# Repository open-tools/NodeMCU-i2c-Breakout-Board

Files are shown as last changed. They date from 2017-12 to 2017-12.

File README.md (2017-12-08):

# NodeMCU I²C and 1-Wire Breakout Board

Have you  ever tried connecting more than one I²C device to a NodeMCU board? While I²C and 1-wire are designed to allow dozens of devices connected to the same bus, most boards - including the NodeMCU - provide only one pin for the I²C lines (SCL and SDA). To connect multiple I²C devices, one usually needs to resolve to clumsy breadboards.

This board is a simple, small breakout board for the NodeMCU, which is attached to only one side of the NodeMCU. It provides multiple I²C and 1-wire connections. The pin order of the I²C connectors is the one used by most I²C sensors:
* VCC
* GND
* SCL
* SDA

Please note that the SparkFun sensors use a different order!

The pin order of the 1-Wire connectors is:
* GND
* DATA
* VCC

One can solder either male or female pin headers to the breakout board and connect the sensors using Dupont wires, or use female pin headers with the sensors directly plugged into the breakout board.

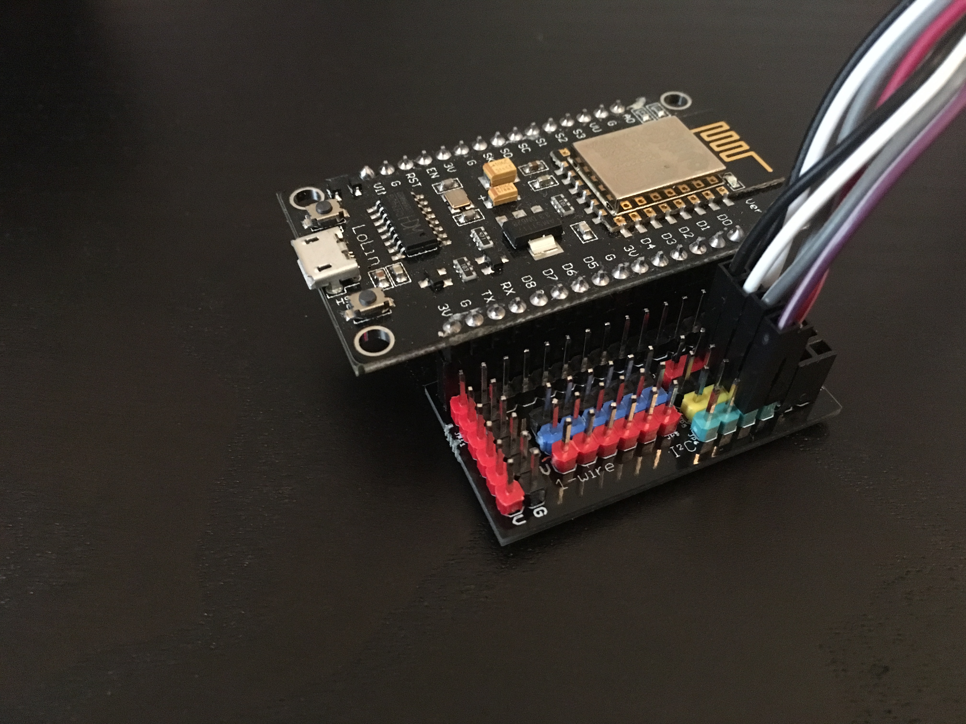
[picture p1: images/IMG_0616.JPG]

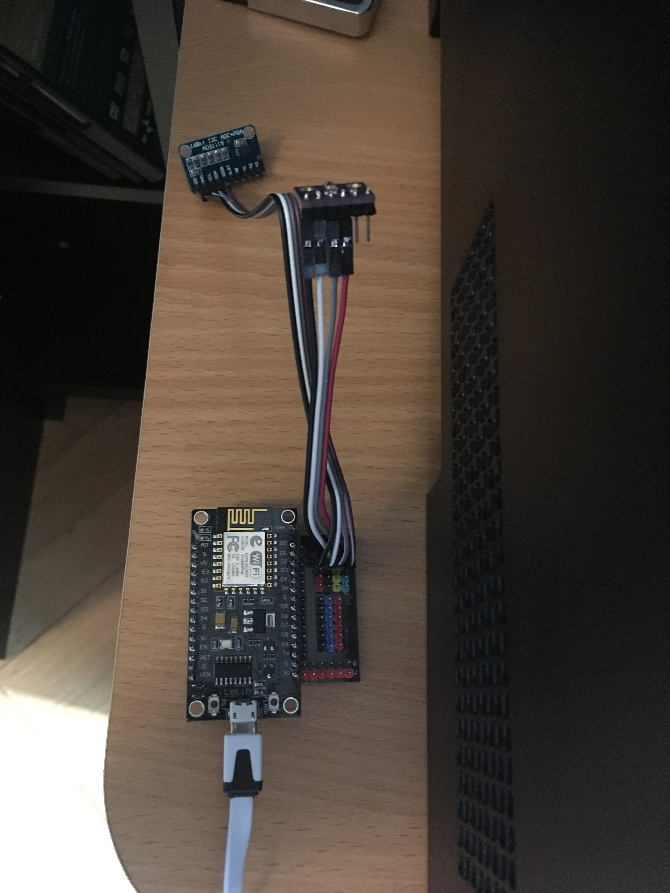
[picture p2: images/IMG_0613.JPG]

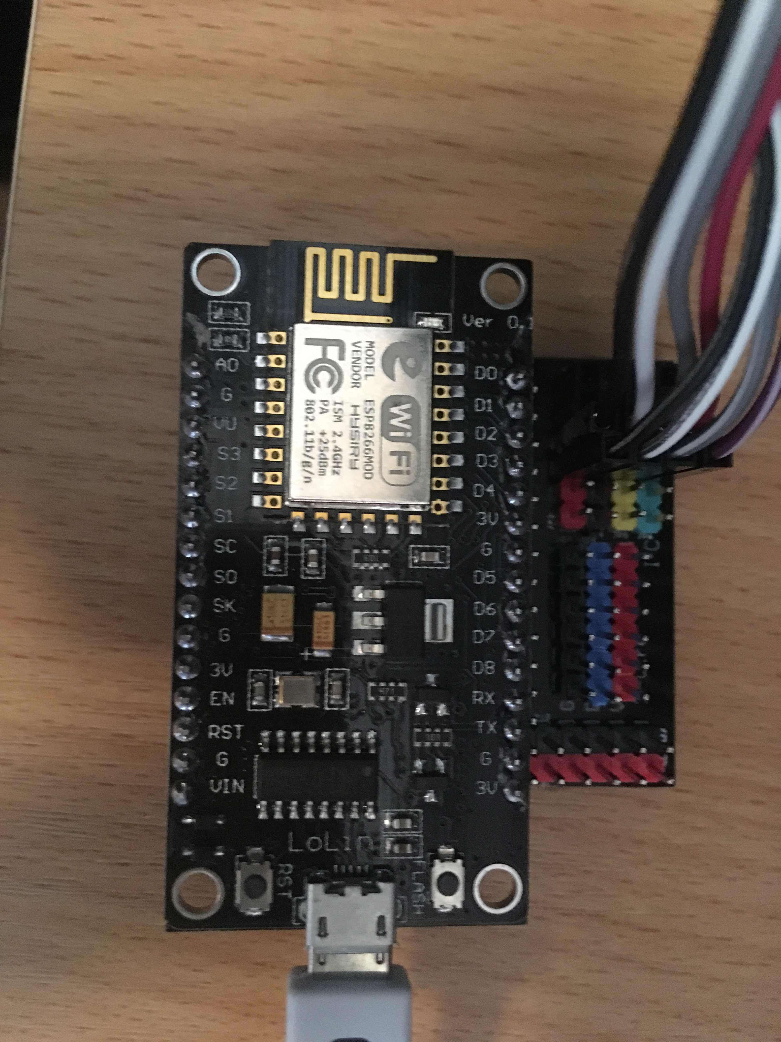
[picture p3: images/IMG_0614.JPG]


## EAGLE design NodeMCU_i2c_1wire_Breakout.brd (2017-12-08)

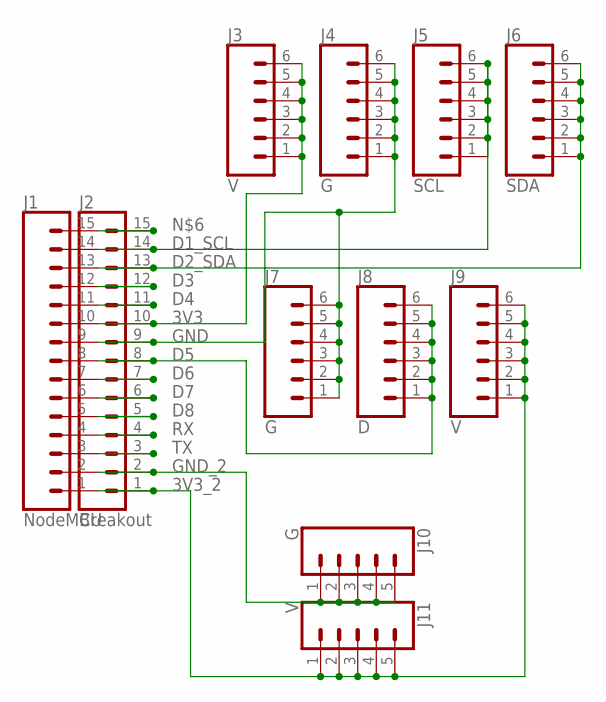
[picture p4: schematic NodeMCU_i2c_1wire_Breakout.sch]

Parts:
J1: NodeMCU; 1X15
J2: Breakout; 1X15
J3, J9: V; 1X06
J4, J7: G; 1X06
J5: SCL; 1X06
J6: SDA; 1X06
J8: D; 1X06
J10: G; 1X05
J11: V; 1X05

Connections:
3V3: J1.10, J2.10, J3.1, J3.2, J3.3, J3.4, J3.5, J3.6
3V3_2: J1.1, J2.1, J9.1, J9.2, J9.3, J9.4, J9.5, J9.6, J11.1, J11.2, J11.3, J11.4, J11.5
D1_SCL: J1.14, J2.14, J5.1, J5.2, J5.3, J5.4, J5.5, J5.6
D2_SDA: J1.13, J2.13, J6.1, J6.2, J6.3, J6.4, J6.5, J6.6
D3: J1.12, J2.12
D4: J1.11, J2.11
D5: J1.8, J2.8, J8.1, J8.2, J8.3, J8.4, J8.5, J8.6
D6: J1.7, J2.7
D7: J1.6, J2.6
D8: J1.5, J2.5
GND: J1.9, J2.9, J4.1, J4.2, J4.3, J4.4, J4.5, J4.6, J7.1, J7.2, J7.3, J7.4, J7.5, J7.6
GND_2: J1.2, J2.2, J10.1, J10.2, J10.3, J10.4, J10.5
unnamed: J1.15, J2.15
RX: J1.4, J2.4
TX: J1.3, J2.3

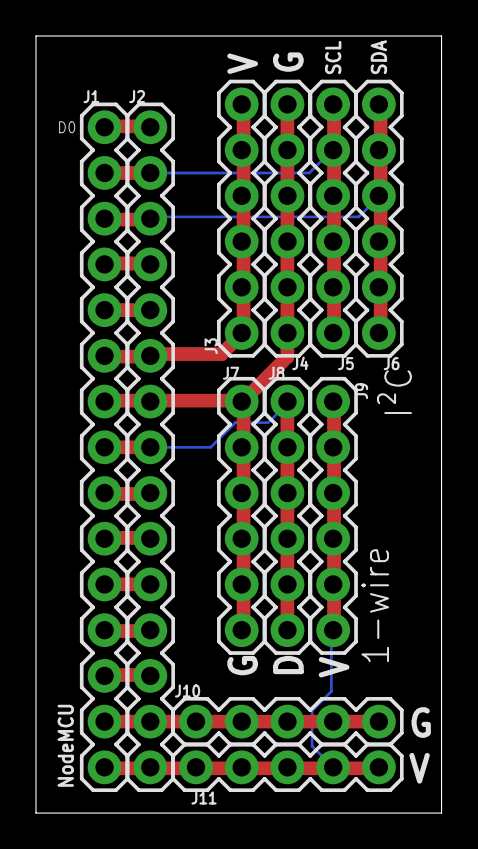
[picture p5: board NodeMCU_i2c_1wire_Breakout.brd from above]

Board: 2 copper layers, 22.5 x 43.2 mm, 11 parts (0 on the bottom side), 15 nets.

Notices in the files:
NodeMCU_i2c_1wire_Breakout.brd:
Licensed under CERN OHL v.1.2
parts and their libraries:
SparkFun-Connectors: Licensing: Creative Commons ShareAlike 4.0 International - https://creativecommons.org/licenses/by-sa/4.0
